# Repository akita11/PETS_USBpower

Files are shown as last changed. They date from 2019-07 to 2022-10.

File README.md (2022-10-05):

# PETS_USBpower

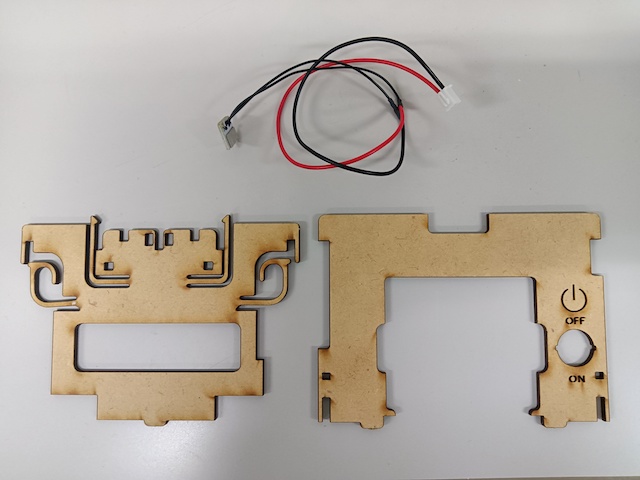
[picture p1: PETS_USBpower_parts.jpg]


[PETS](https://4ok.jp/pets/)をUSBモバイルバッテリで使えるように改造する部品です。

※PETSを分解・改造して使用します。そのため、PETSの製品保証の対象外となります。

# 用意するもの

※モバイルバッテリ以外の部材はスイッチサイエンスで委託販売予定です

* 筐体の板（2枚）：MDF板（厚さ2.5mm）をレーザーカッター等でカットします。（PETS_USBpower: PDFとInkscape SVGで同一内容）

* USBコネクタ：出っ張りが少ないUSBコネクタ（基板）。USBpowerconn_gerber.zipを基板製造サービス等で製造します（板厚は2.0mmとするか、1.6mmのものに裏面に厚紙などをはさんで厚さを調整する）※ケーブルが根本から切れやすいのでグルーガン等で強化したほうがいいです

* 電源ケーブル：JSTのXHコネクタ(2p)＋10cm程度のケーブル ※[aitendo](http://www.aitendo.com)で売っていることがある

* ダイソーで500円売っているUSBモバイルバッテリ（またはそれと同等のサイズのもの）。サイズは120mm x 70mm x 20mm程度以下であれば、収まります。

# 組み立て

[こちらの手順](https://github.com/akita11/PETS_USBpower/blob/master/instruction/README.md)で、PETSを分解・改造します。改造後は、普段どおりのPETSとして使用できます。

# おまけ

PETSblock_holder.{svg/pdf}をダンボール等でカットして組み立てると、PETSのブロックを保存しておくのに使えます。

# Author

Junichi Akita / @akita11 / akita@ifdl.jp

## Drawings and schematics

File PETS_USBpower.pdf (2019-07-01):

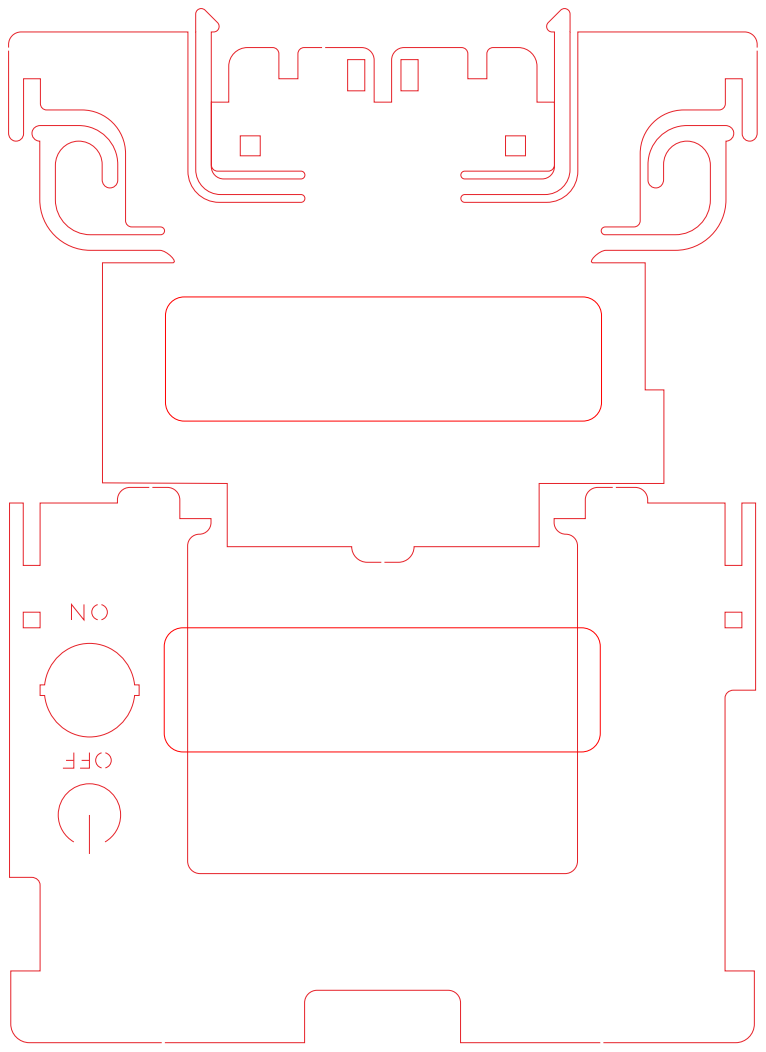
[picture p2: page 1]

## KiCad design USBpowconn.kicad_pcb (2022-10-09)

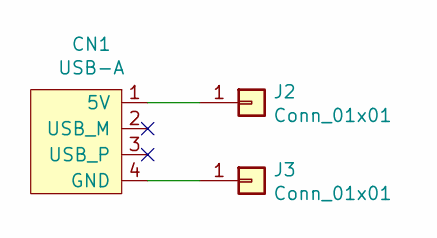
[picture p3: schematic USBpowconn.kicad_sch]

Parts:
CN1: USB-A; USB-A-PCB
J2, J3: Conn_01x01; PinSocket_1x01_P2.54mm_Vertical

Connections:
unnamed: CN1.1 (5V), J2.1
unnamed: CN1.4 (GND), J3.1

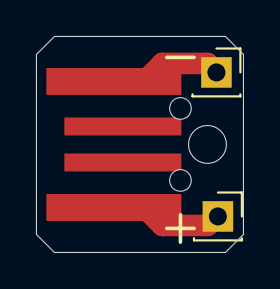
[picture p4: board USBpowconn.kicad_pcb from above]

Board: 2 copper layers, 11.5 x 12.0 mm, 3 parts (0 on the bottom side), 2 nets.

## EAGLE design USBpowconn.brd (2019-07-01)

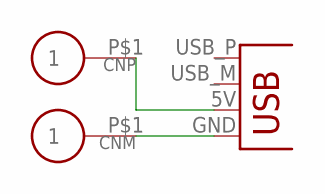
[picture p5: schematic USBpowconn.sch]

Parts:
CNM: CON_P01TH09MM; PAD_TH09MM
CNP: CON_P01TH09MM; PAD_TH09MM
JP1: CON_USBPCB; USB-A-PCB

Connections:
unnamed: CNP.P$1, JP1.5V (VBUS)
unnamed: CNM.P$1, JP1.GND

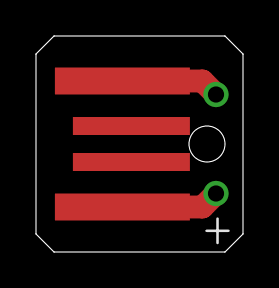
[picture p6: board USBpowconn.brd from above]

Board: 2 copper layers, 11.5 x 12.0 mm, 3 parts (0 on the bottom side), 2 nets.

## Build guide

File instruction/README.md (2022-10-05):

# PETSの分解・改造の手順

## 分解

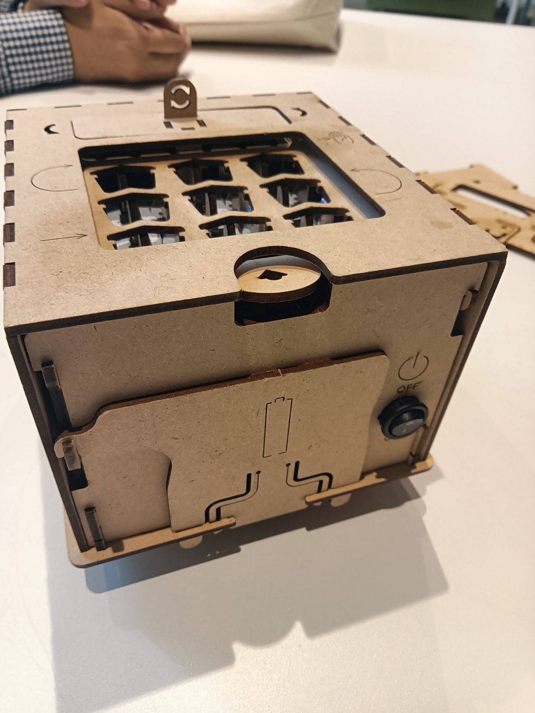
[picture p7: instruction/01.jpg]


PETS後面

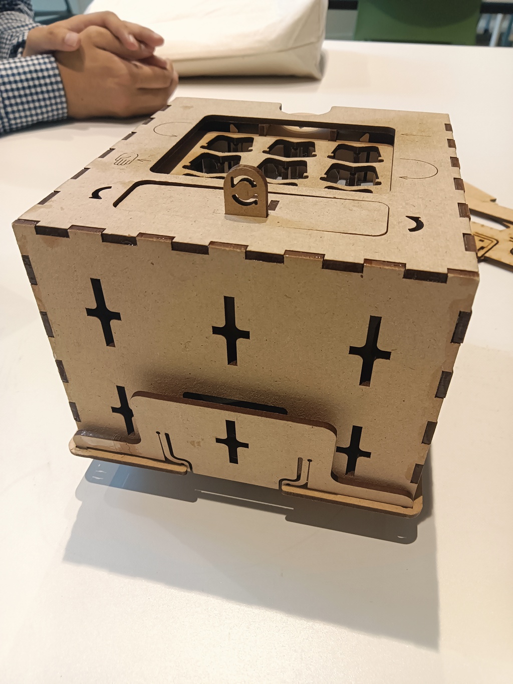
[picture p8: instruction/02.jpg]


PETS前面

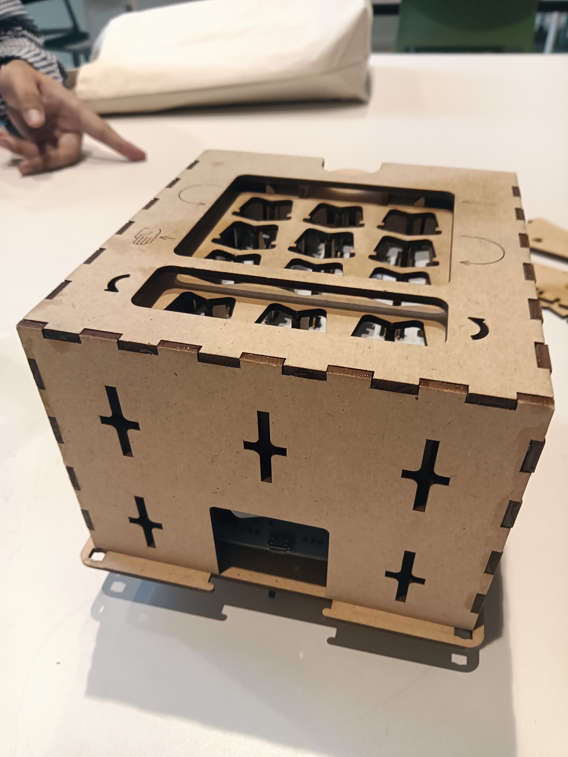
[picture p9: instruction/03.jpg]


前面の下部の板をはずす

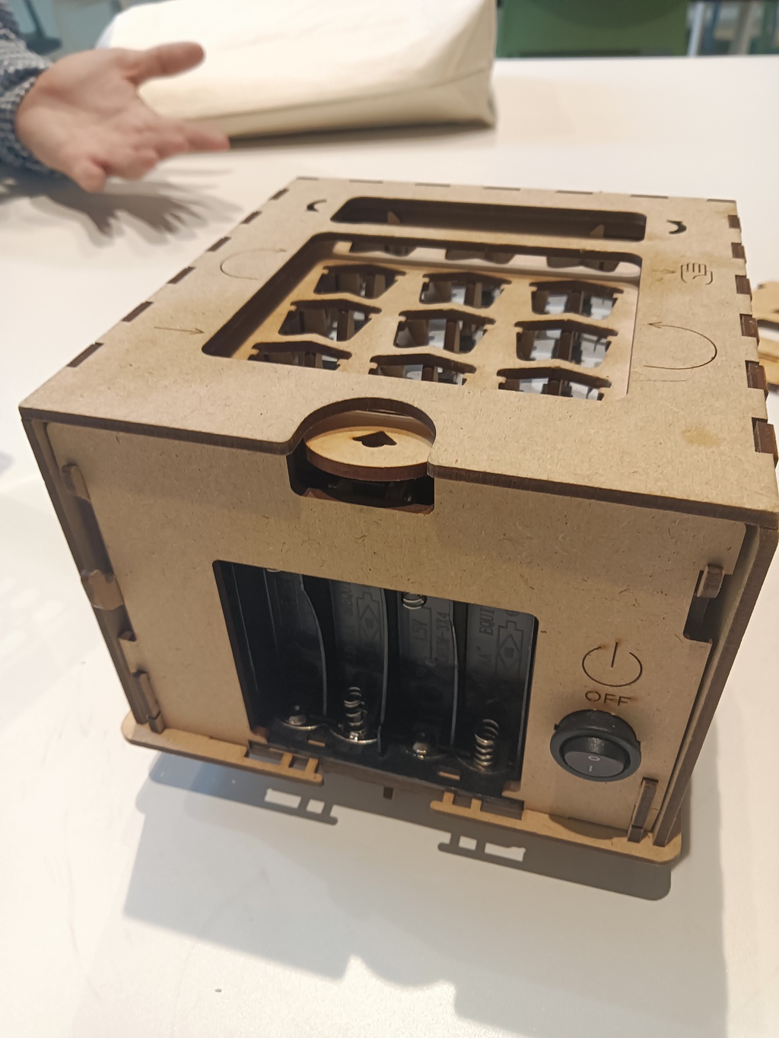
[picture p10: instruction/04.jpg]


後面の電池カバー板をはずす

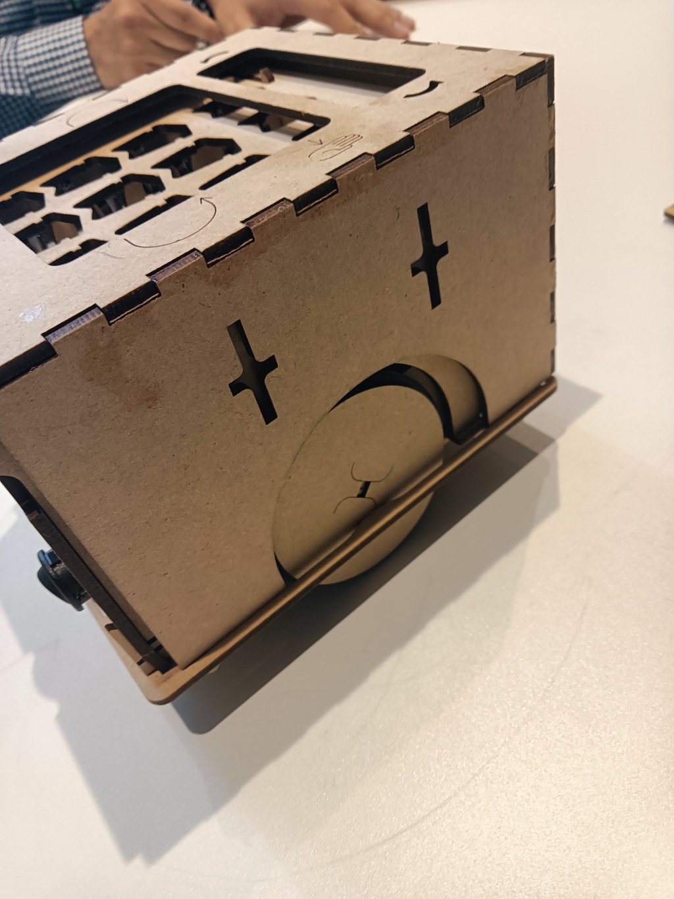
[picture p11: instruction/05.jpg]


繰り返しブロック部のカバーをはずし、本体カバーを少し前方へずらす

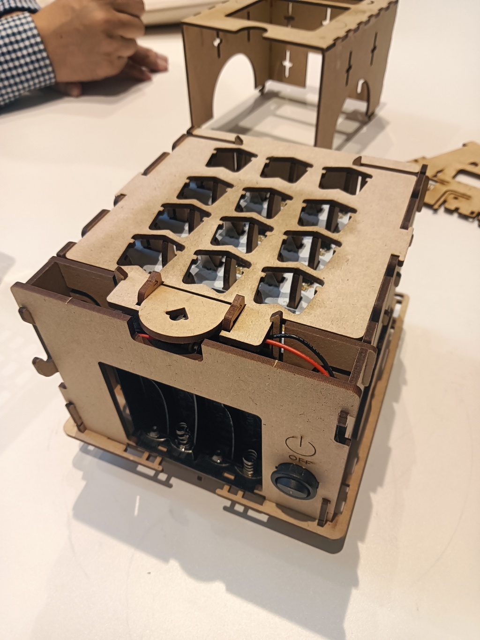
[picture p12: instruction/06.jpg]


本体カバーを上に持ち上げてはずす

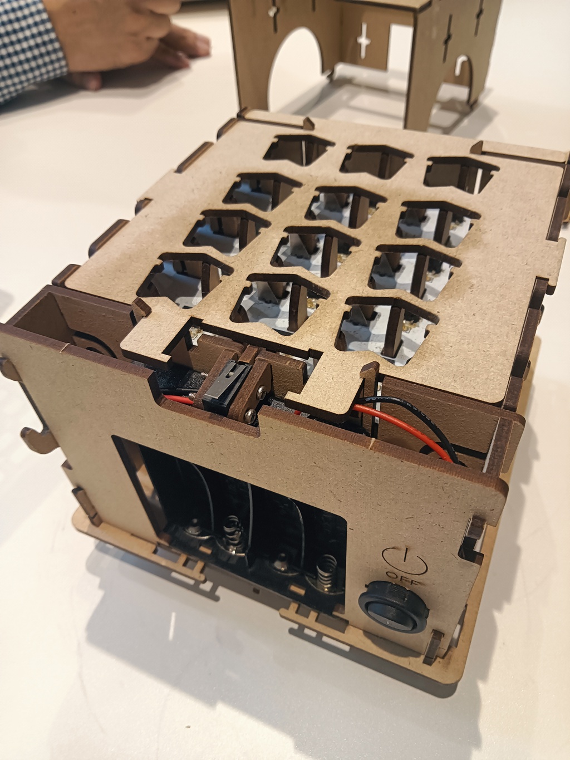
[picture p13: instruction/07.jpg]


スイッチレバーを外す

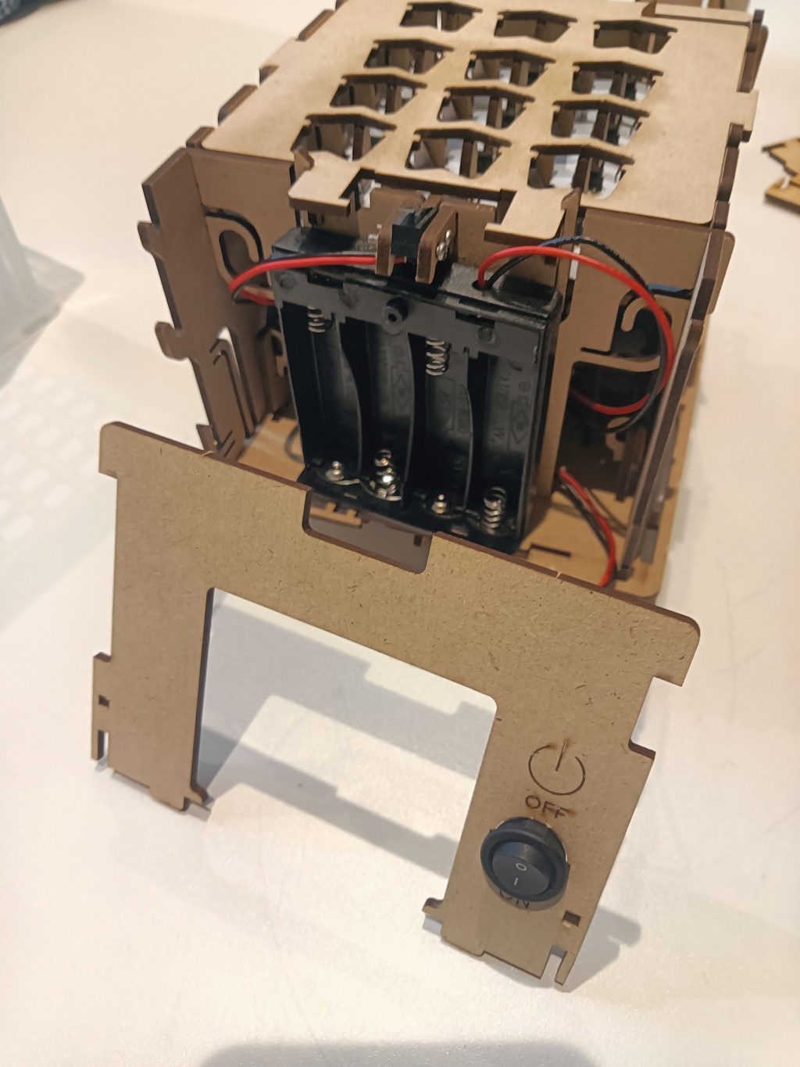
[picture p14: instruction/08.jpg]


後面の板を、下部などの固定突起を少しずらしながらはずす

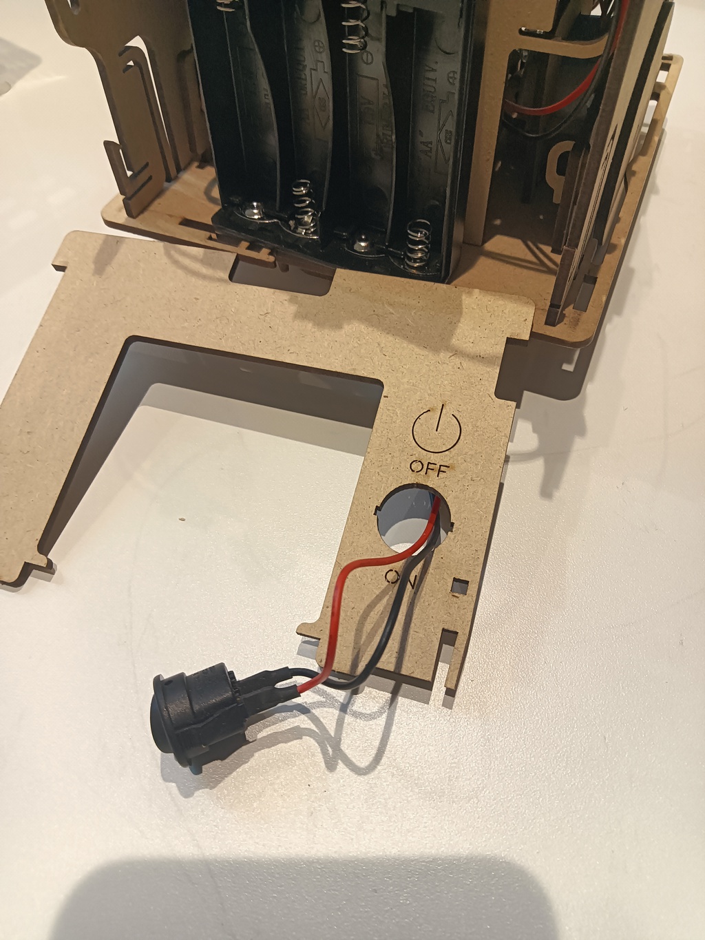
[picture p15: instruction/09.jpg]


電源スイッチの裏面のツメを押しながら引き出してはずす。ペンチなどをで抑えるとはずしやすい。硬いので注意。

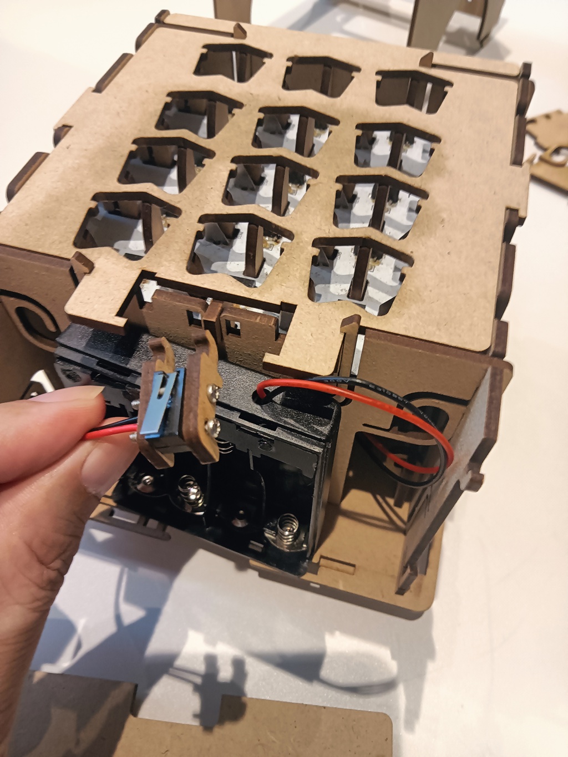
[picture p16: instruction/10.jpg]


スイッチをはずす

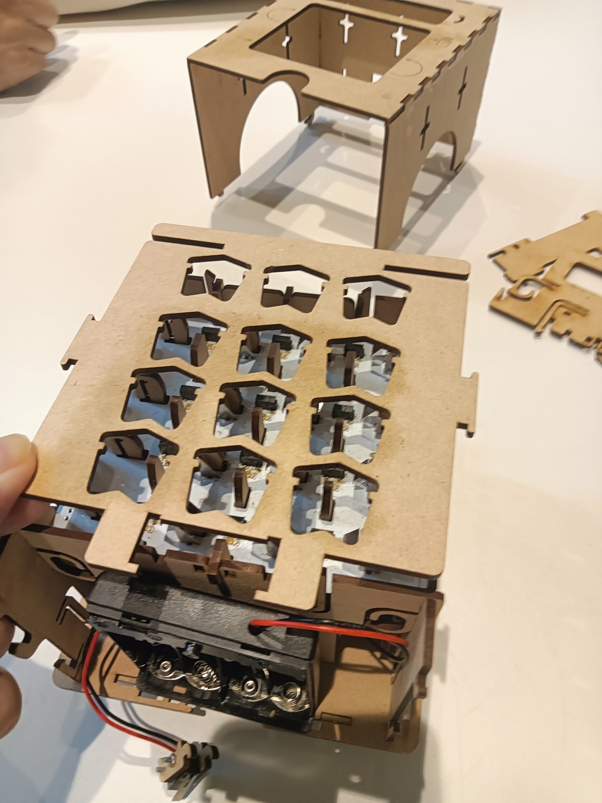
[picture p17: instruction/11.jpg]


上面の板を、両側にあるツメを押しながら持ち上げてはずす

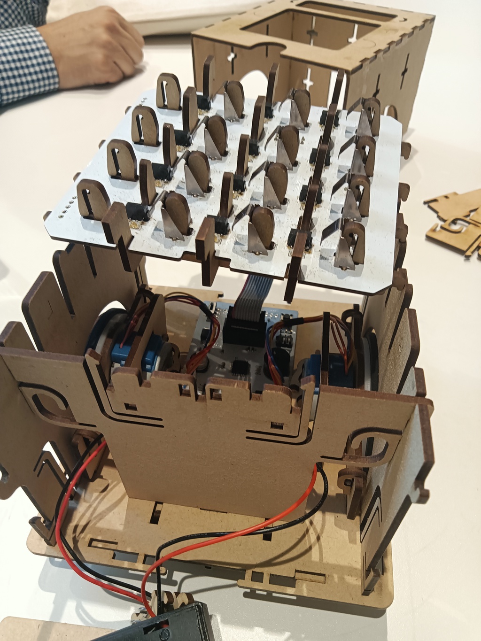
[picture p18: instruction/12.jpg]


ブロックがささる部分の白い基板を持ち上げてはずす

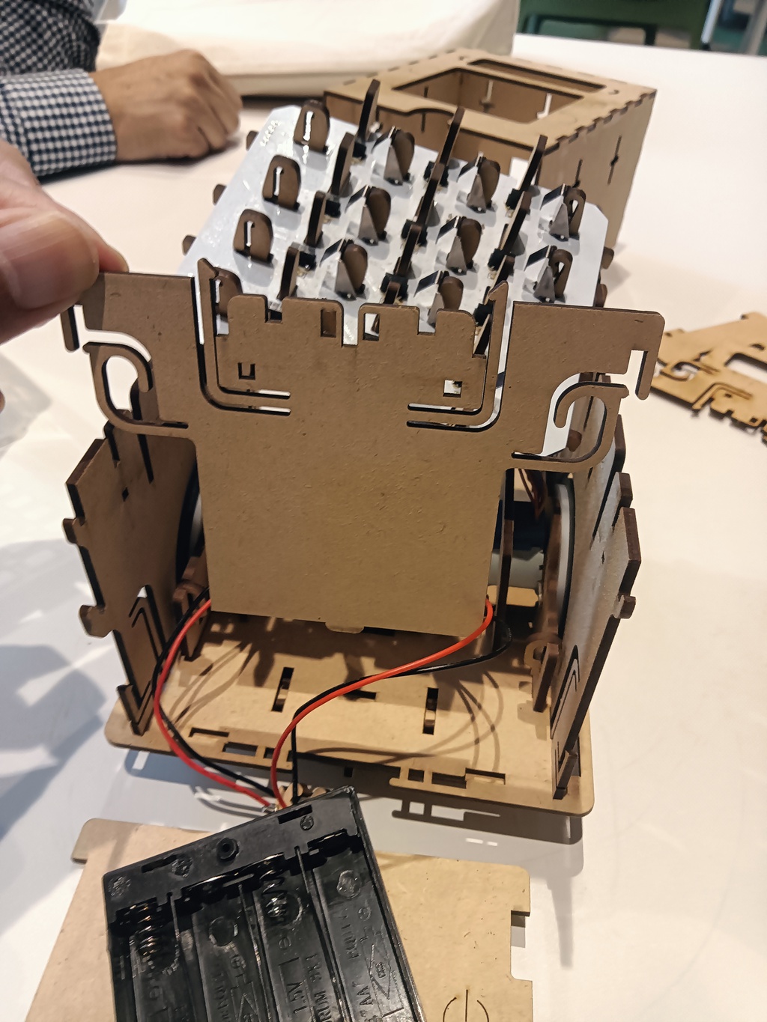
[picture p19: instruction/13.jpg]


後面の一つ奥にあるこの板を、ツメを押しながら持ち上げてはずす

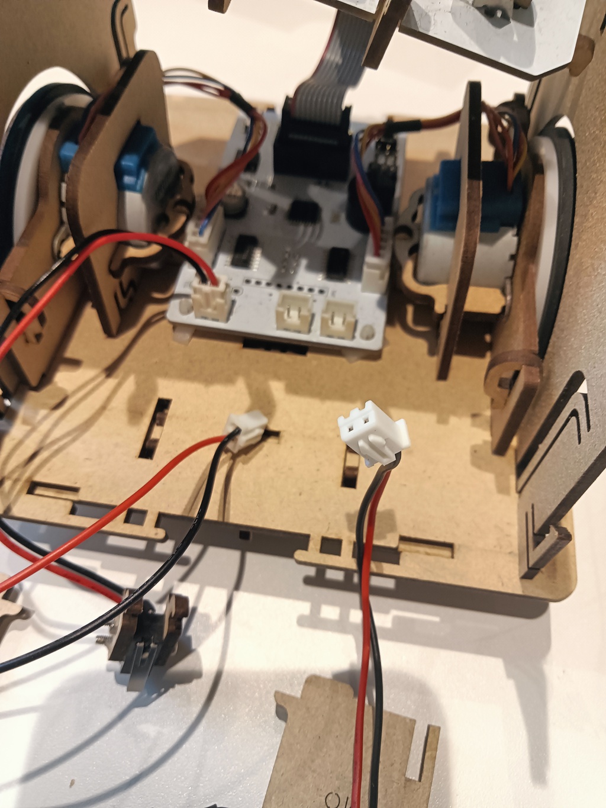
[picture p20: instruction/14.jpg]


BAT、SWの2つのコネクタを引き抜いてはずす

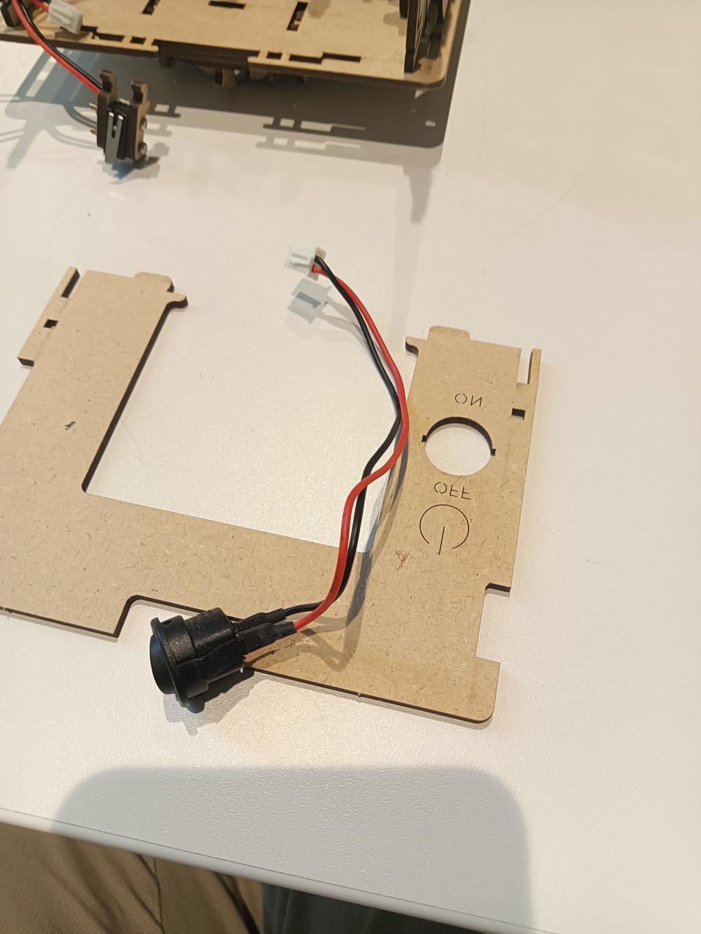
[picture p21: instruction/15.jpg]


電源スイッチのケーブルを板から抜いて、板と分離する

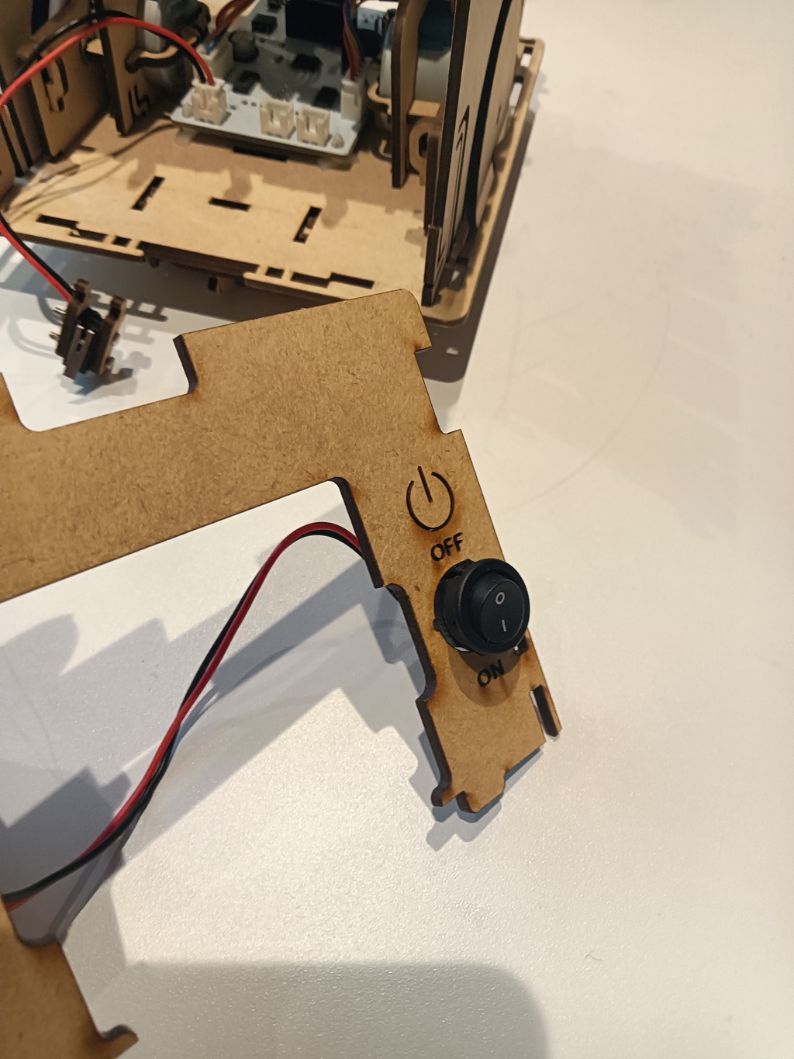
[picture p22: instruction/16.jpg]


## 改造と復旧

交換用板1に電源スイッチを押し込む。スイッチの上下の向きに注意。

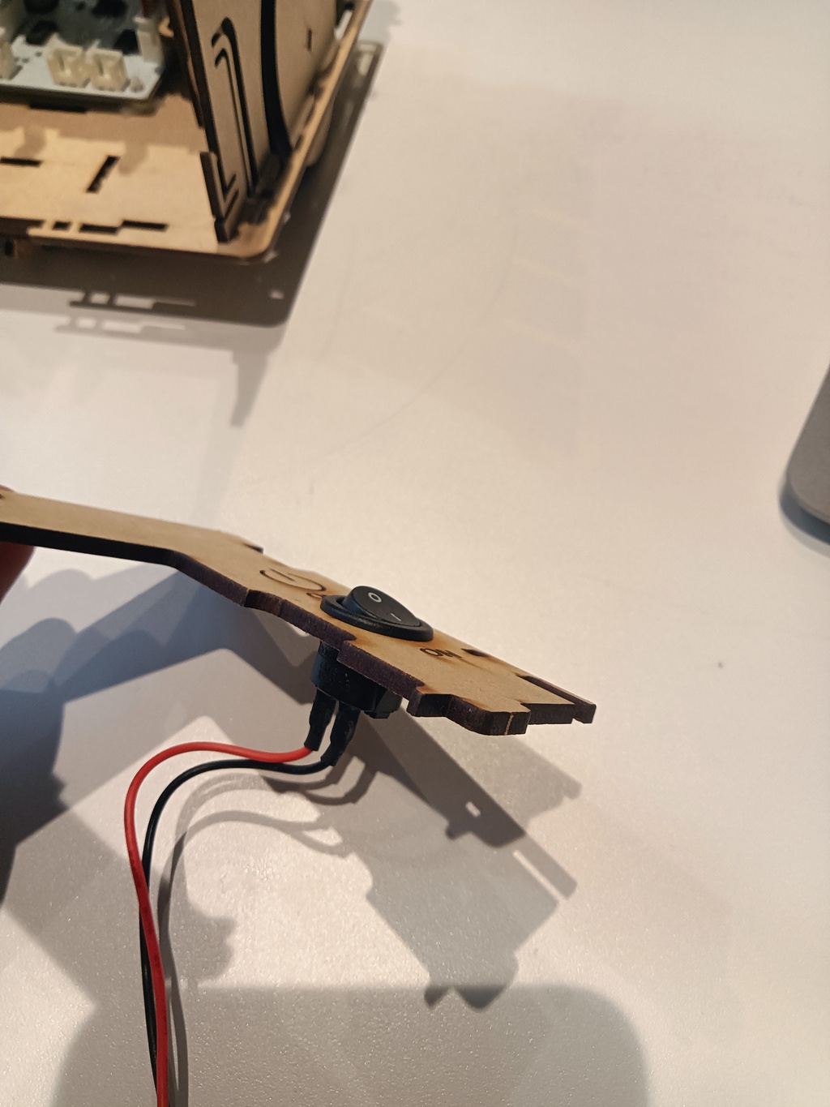
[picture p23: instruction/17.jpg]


ツメで固定されるまで、奥まで完全に押し込んで固定する

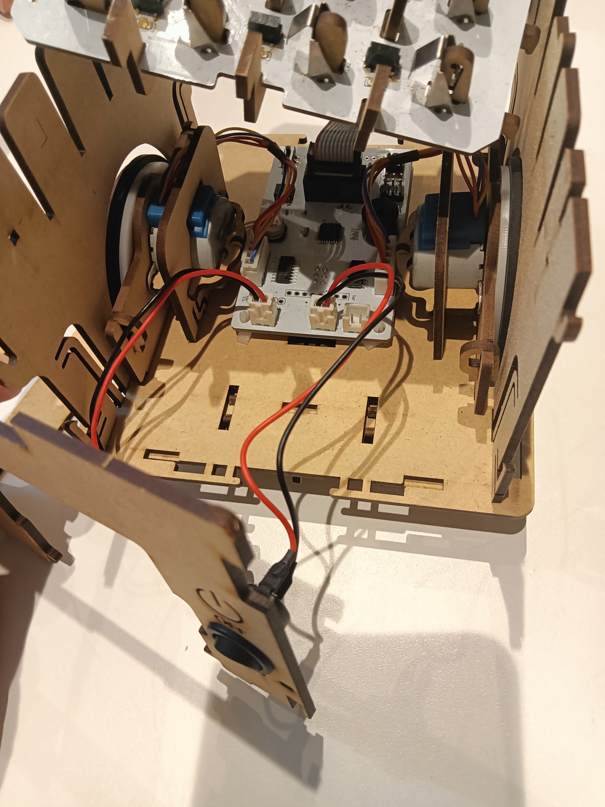
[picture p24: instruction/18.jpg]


電源スイッチのケーブル端のコネクタを本体ボードのSWコネクタに差し込む

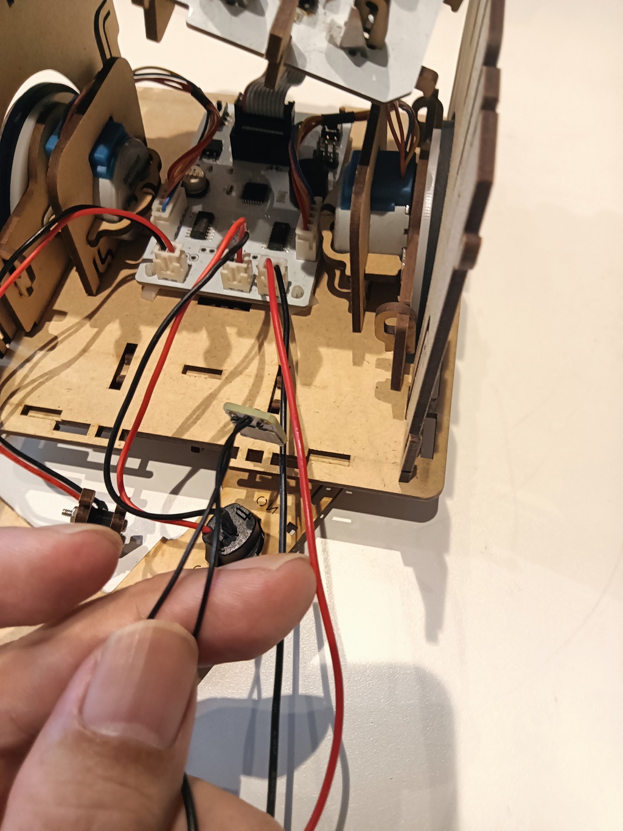
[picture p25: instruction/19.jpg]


USBケーブルの端のコネクタをを本体ボードのBATコネクタに差し込む

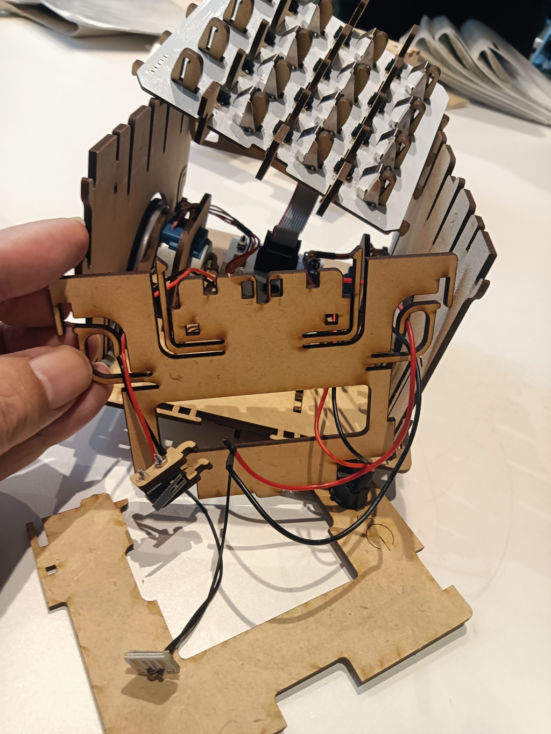
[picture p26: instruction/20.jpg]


スイッチのケーブルを、交換用板2のこの分の隙間に通す

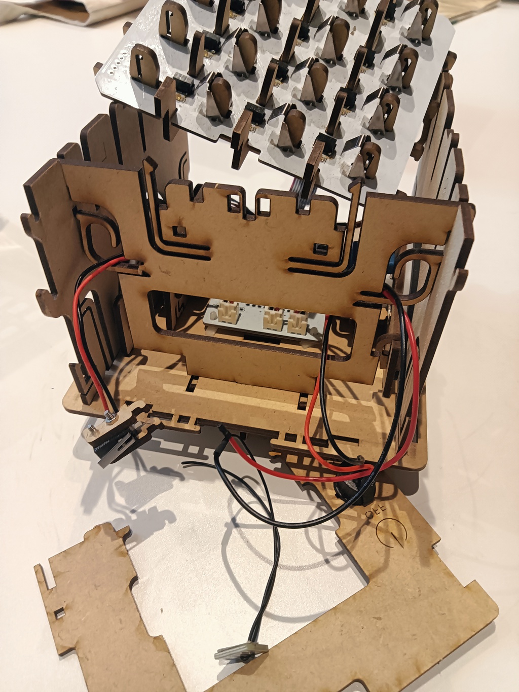
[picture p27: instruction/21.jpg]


交換用板2を本体にはめる。両側のツメで固定されるまで下へ差し込む。

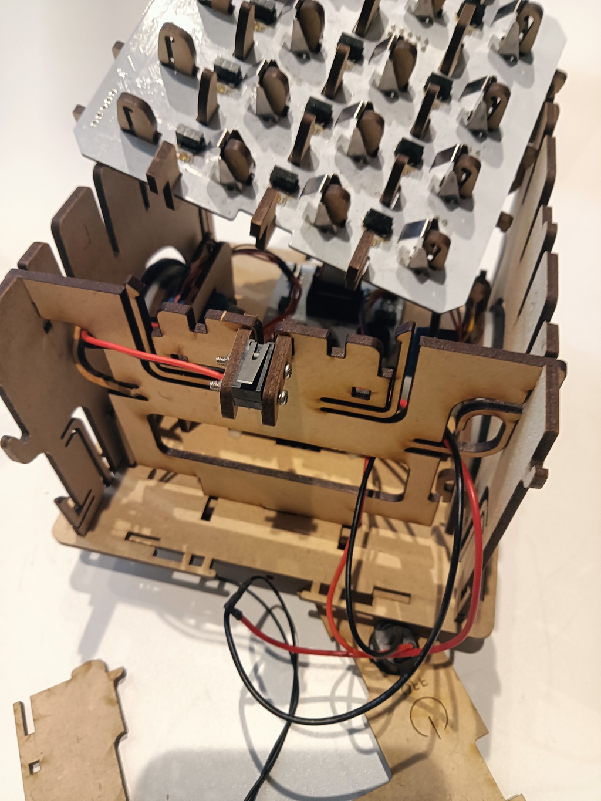
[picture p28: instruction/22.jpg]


スイッチをとりつける

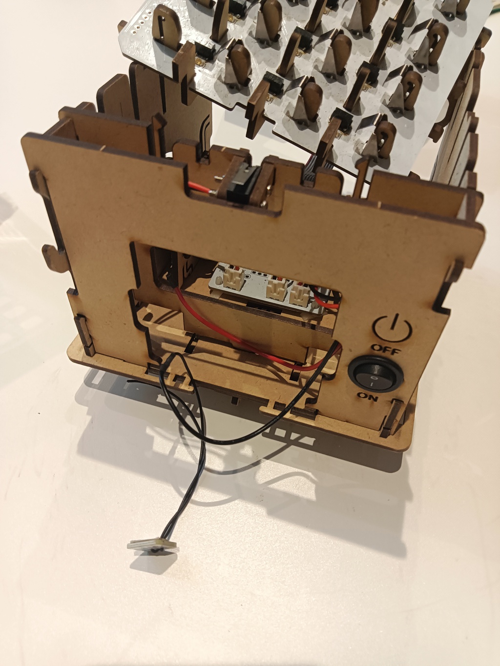
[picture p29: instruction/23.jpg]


交換用板1を本体にはめる。両側のツメで固定されるまで下へ差し込む。

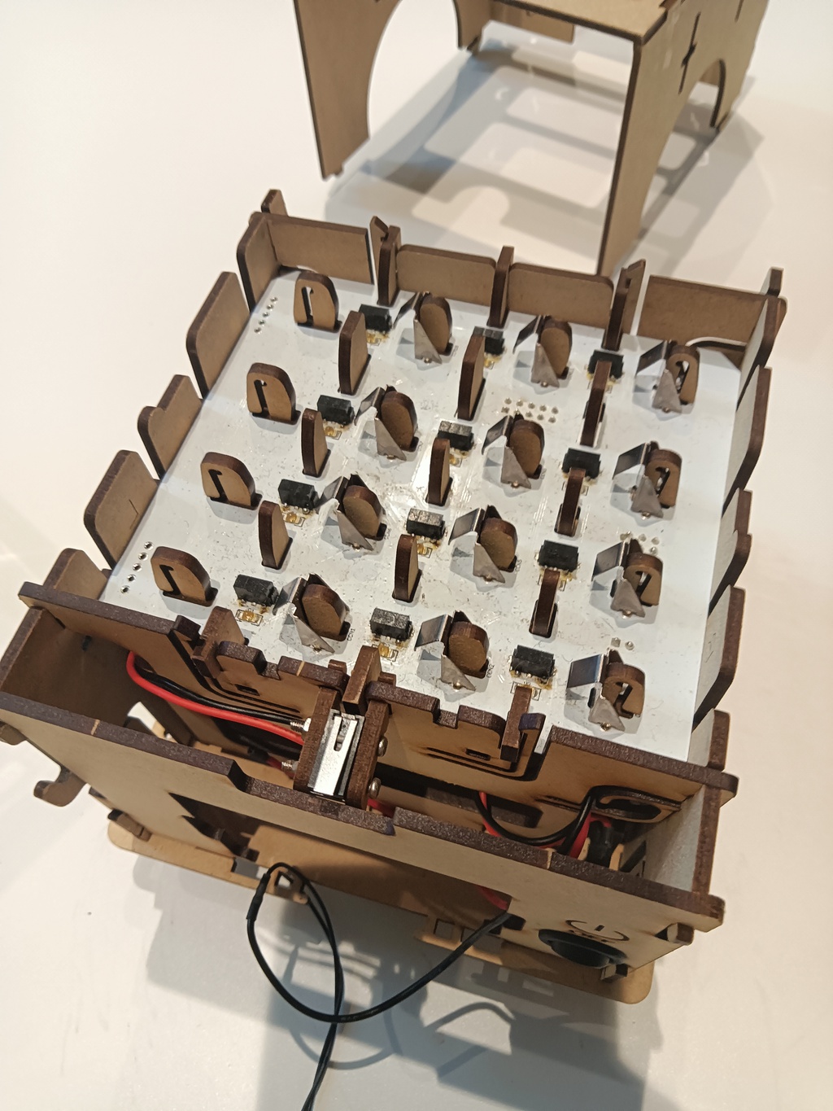
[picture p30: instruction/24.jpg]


ブロックがささる部分の白い基板を戻す。両側のツメで固定されるようにする

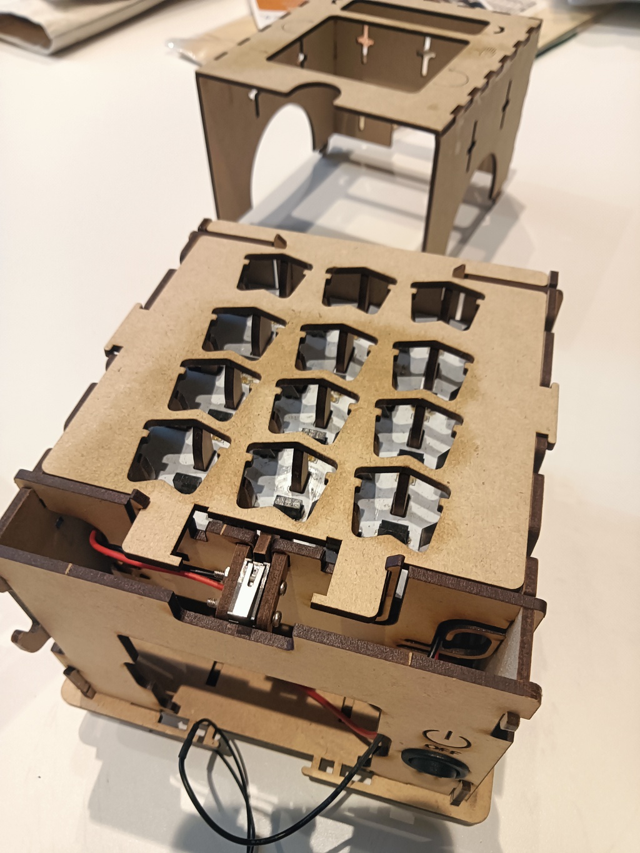
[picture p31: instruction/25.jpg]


上面の板を戻す。両側のツメで固定されるようにする

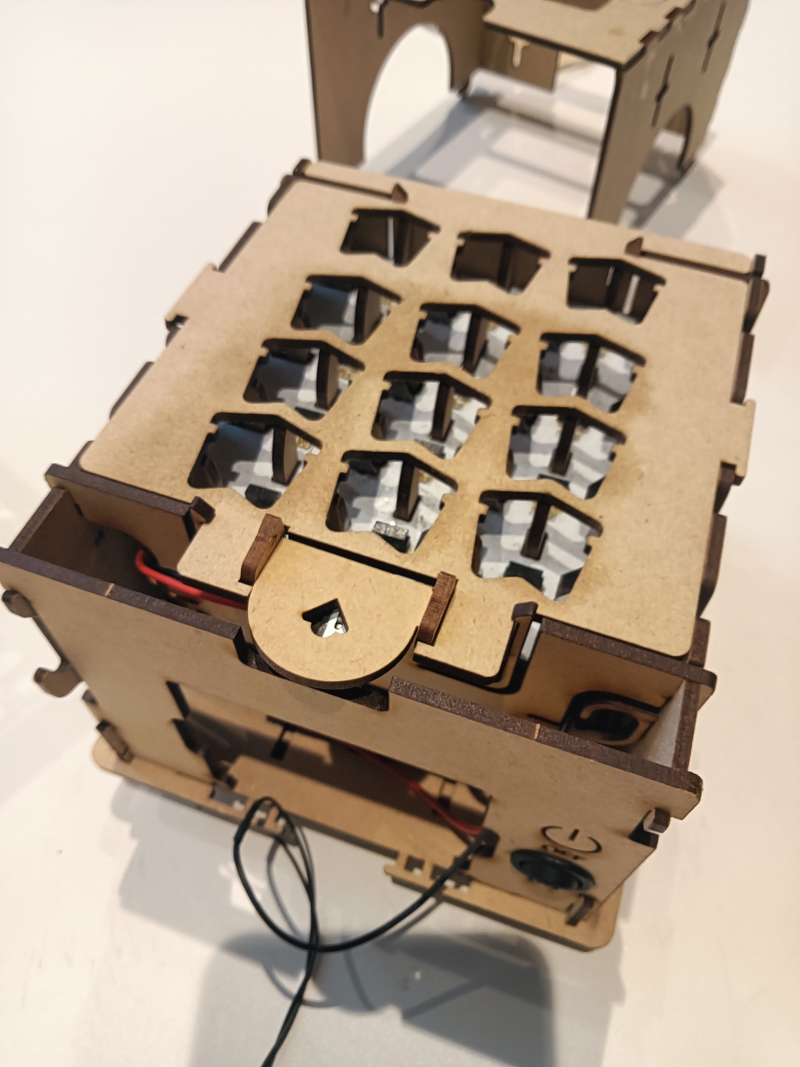
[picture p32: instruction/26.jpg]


スイッチレバーを戻す。両側の部品の円弧の部分が下側になるように置く。

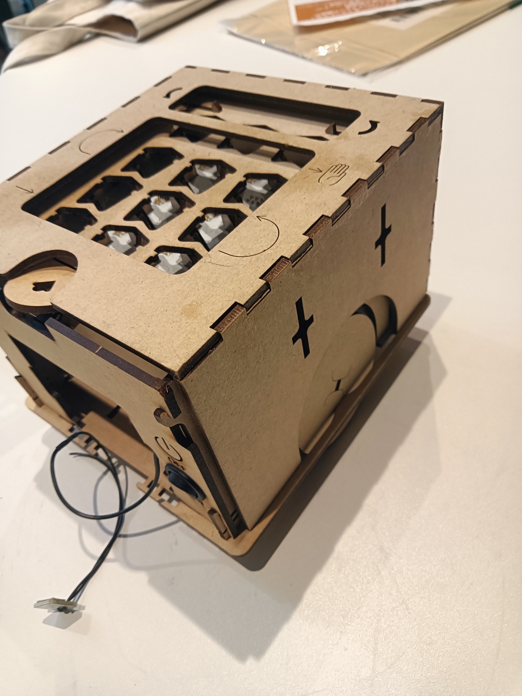
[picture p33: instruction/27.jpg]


本体カバーを差し込み、最初の位置までずらして固定する

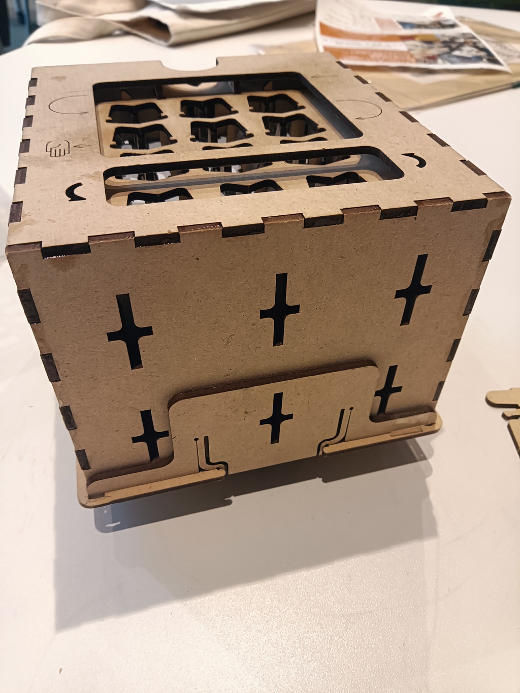
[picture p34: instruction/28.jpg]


前面の下部の板を戻す

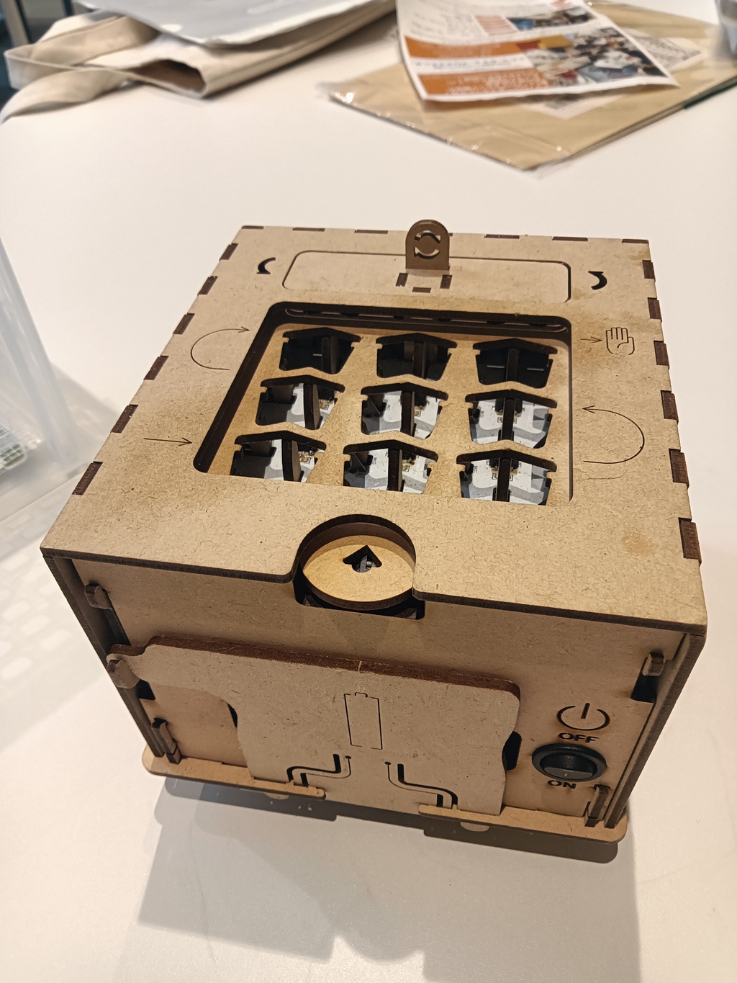
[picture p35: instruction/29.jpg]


USBモバイルバッテリにUSBケーブルを接続し、後面の電池カバーを戻す。

以上で終わりです。お疲れさまでした！

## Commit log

2019-07-01 1st commit
    [USBpowconn.brd, USBpowconn.sch]
2019-07-01 画像URLを修正
2021-03-05 README.mdも誤字を修正
2022-10-09 add USB connector back
